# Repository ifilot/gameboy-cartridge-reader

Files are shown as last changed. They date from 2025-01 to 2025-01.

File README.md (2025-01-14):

# Gameboy Cartridge Reader






This project is a Gameboy cartridge reader designed around the Atmel ATmega32u4
microcontroller. It provides an easy way to interface with Gameboy cartridges,
enabling data reading, writing, and backup. The design includes a custom PCB,
firmware for the 32u4, and a simple GUI for user interaction.

> [!NOTE]
> Download a Windows 64-bit installer for the GUI [via this link](https://github.com/ifilot/gameboy-cartridge-reader/releases/latest/download/gbcr-installer-win64.exe)

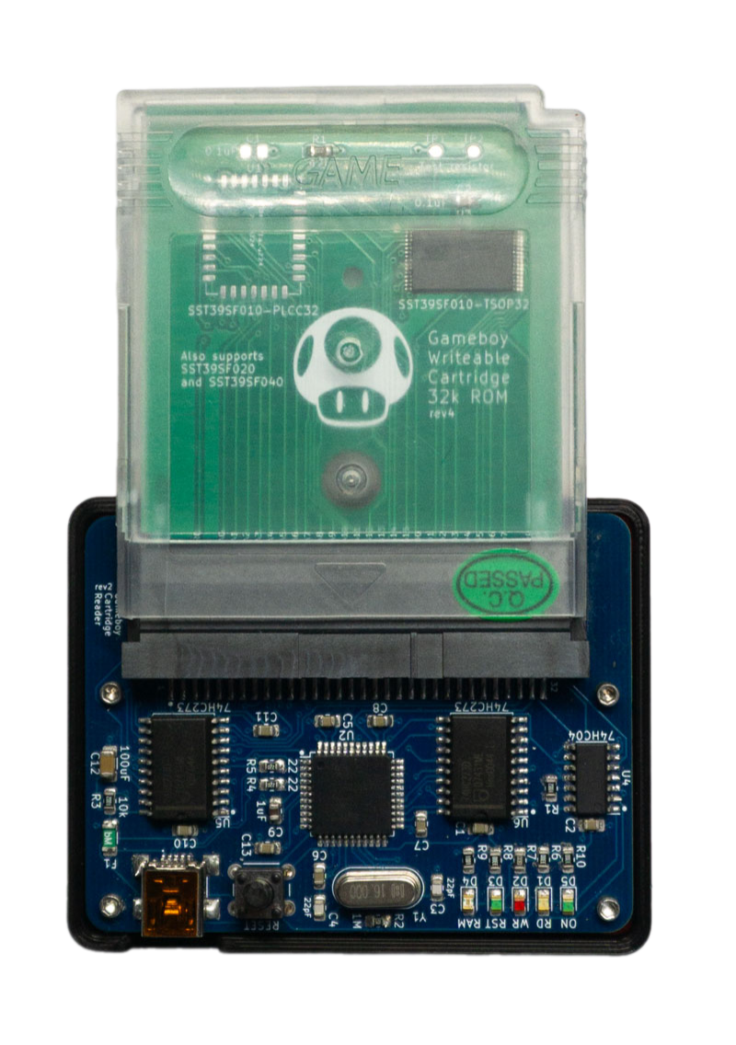
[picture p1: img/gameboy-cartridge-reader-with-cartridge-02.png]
PCB with components


## Features

* **Custom PCB**: Compact and optimized PCB designed for seamless connection with
  Gameboy cartridges and the 32u4.
* **Firmware**: Lightweight firmware written for the ATmega32u4, handling cartridge
  communication and USB interfacing.
* **GUI**: User-friendly graphical interface to manage cartridge data operations on
  your computer.
* **Open Source**: All design files, firmware, and GUI are open-source and available
  for modification.
* **Writable Cartridge Support**: Includes a [PCB design](pcb/gb-cart-sst39sf010/) 
  with an SST39SF010 chip, enabling the writing of 32KiB Gameboy games.
* **Gameboy Camera Support**: Easily extract photos taken with the 
  [Gameboy Camera](https://en.wikipedia.org/wiki/Game_Boy_Camera)
  and save them on your computer. The extracted images can be exported in a 
  variety of color palettes for a personalized look.

> [!IMPORTANT] 
> Please be aware of copyright laws regarding Gameboy and Gameboy
> Color games. Making copies of game data is strictly prohibited in many
> countries unless you own the original cartridge and are creating a backup for
> personal use where such actions are legally permitted. It is your
> responsibility to ensure compliance with local laws. This project is intended
> solely for **educational purposes** and **lawful personal** use.

## GUI

The GUI allows users to interact with their Gameboy cartridges through a
straightforward interface. Users can read ROM data from cartridges, create
backups of save files, and write new save files to supported cartridges.
Additionally, the GUI provides options for verifying data integrity, viewing
cartridge metadata (such as title and game ID), and managing writable cartridges
for flashing custom or homebrew games. Designed for simplicity, the GUI ensures
that all operations are intuitive and accessible, even for beginners.

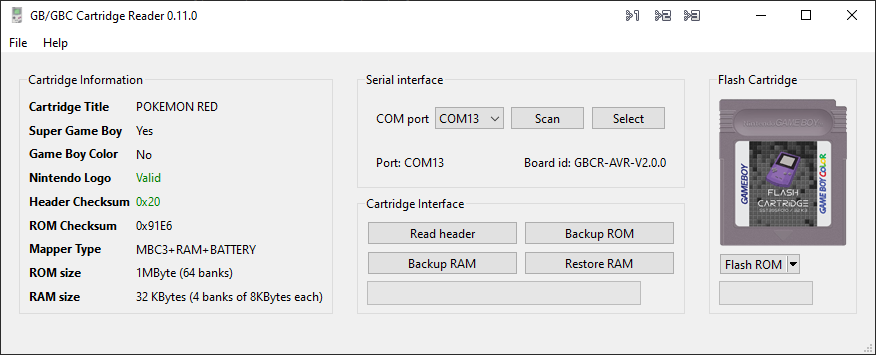
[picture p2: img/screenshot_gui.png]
Graphical User Interface


## Bundled games

The following games are bundled with the GUI and can be readily flashed by the
user to a writeable cartridge.

* [Quartet](https://makrill.itch.io/quartet)
* [Flappybird](https://github.com/pashutk/flappybird-gameboy)

## PCB

The PCB primarily utilizes SMD components, with the exception of the 16MHz
crystal and the push button, which are through-hole components. To simplify the
soldering process, it is recommended that users order a solder paste stencil and
use a hot plate to solder the SMD components efficiently and accurately.

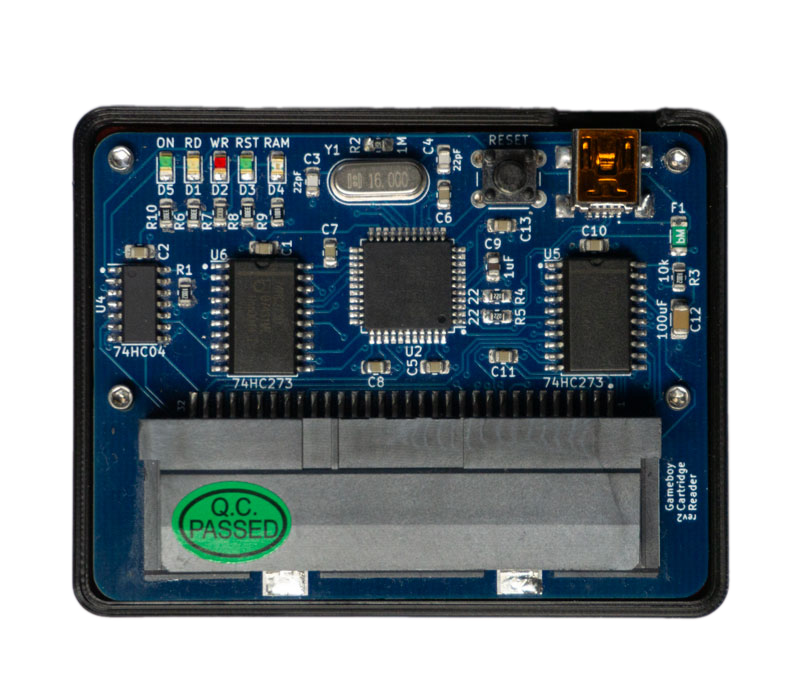
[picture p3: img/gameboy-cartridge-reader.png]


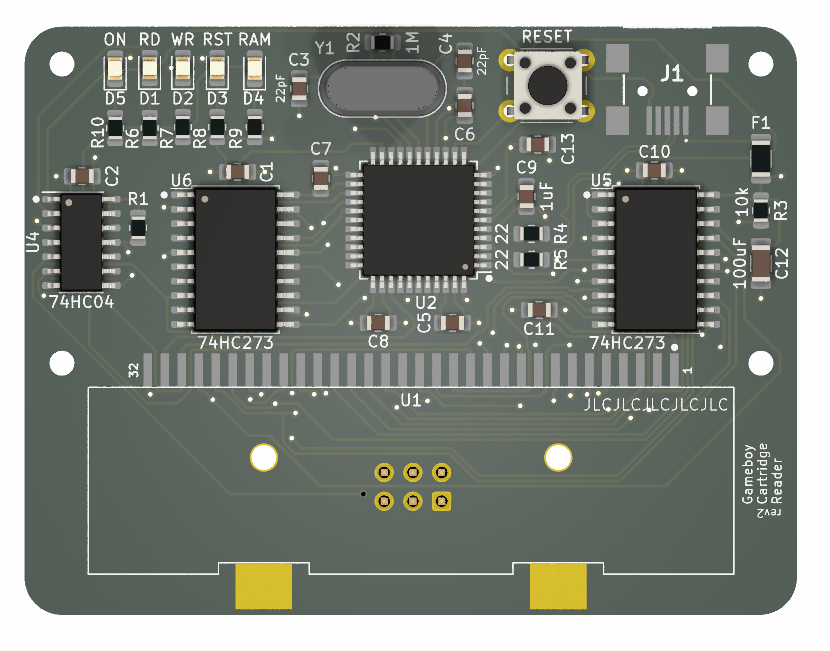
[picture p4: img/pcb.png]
PCB


### Schematic

PCB schematic

### Writeable cartridge

The writable cartridge for the Game Boy, based on the SST39SF010 flash memory
chip, offers versatile support for both TTSOP32 and PLCC32 package variants.
This flexibility allows developers and enthusiasts to choose their preferred
chip packaging without requiring additional hardware modifications. The
cartridge is designed to leverage the high-speed erase and write capabilities of
the SST39SF010, making it ideal for prototyping or homebrew games.

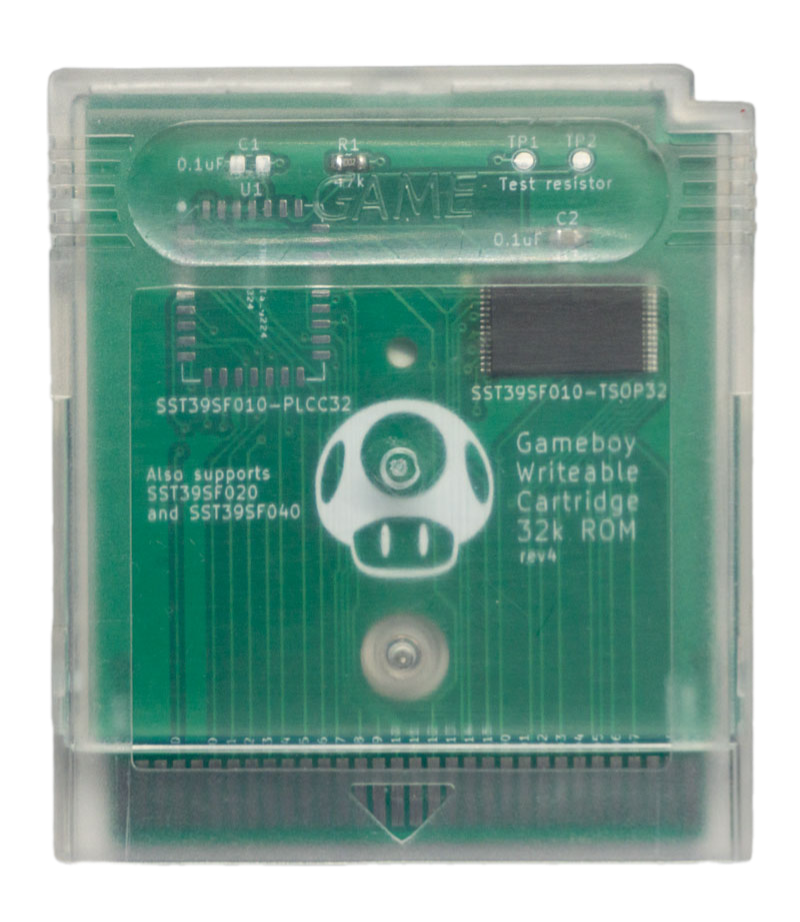
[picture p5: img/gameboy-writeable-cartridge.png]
Writeable cartridge


## Gameboy Camera Features

* Extract images directly from the Gameboy Camera cartridge.
* Customize the color scheme of the extracted photos.
* Preserve your Gameboy Camera creations in digital form.

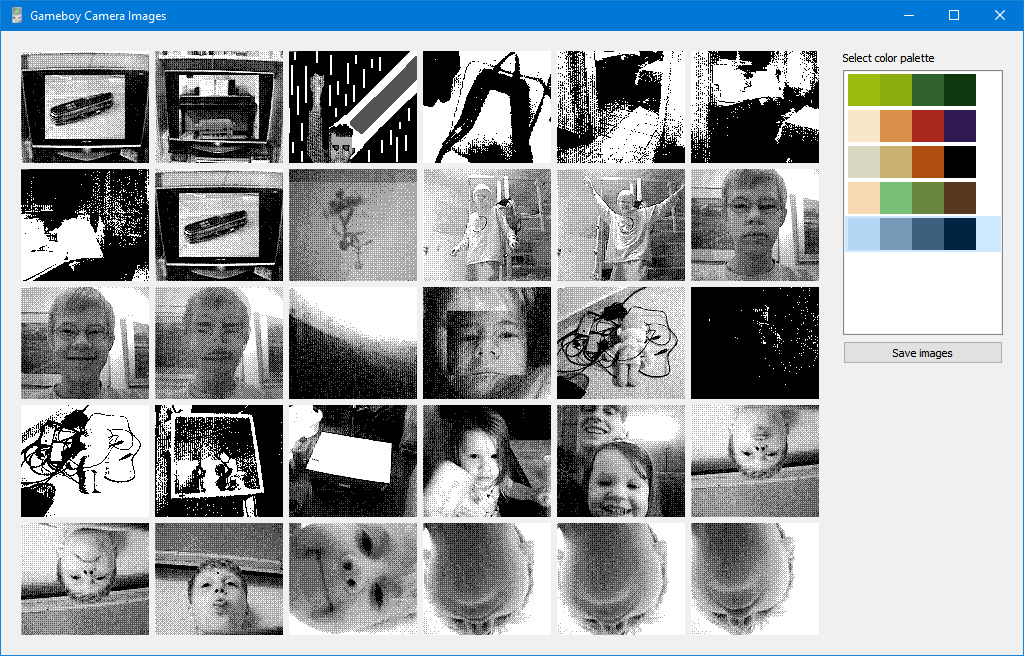
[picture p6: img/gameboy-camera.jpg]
Gameboy Camera


## Firmware

The firmware for the ATmega32u4 must be compiled using Atmel Studio to ensure
compatibility and proper optimization. Once compiled, the firmware can be
flashed to the microcontroller using an ISP programmer, such as AVRDUDE, for
seamless and reliable programming.

### Fuses

See the `firmware/<DEVICE>/scripts` folder for reading and writing the fuses. 
The proper fuse settings for `lfuse`, `hfuse` and `efuse` should 
be `0xFF`, `0xD8` and `0xCB`, respectively.

## Case

A 3D-printable case for the Gameboy cartridge reader is available in the
[cases](cases) folder, providing a protective and aesthetically pleasing
enclosure for the assembled PCB.

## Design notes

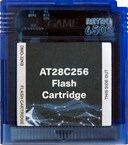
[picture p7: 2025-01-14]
gui/img/at28c256_flash_cartridge.png

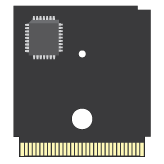
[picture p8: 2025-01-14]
gui/img/flash_cartridge_unknown.png

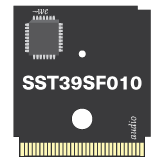
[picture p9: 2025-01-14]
gui/img/flash_cartridge_sst39sf010.png

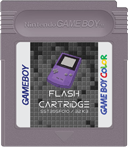
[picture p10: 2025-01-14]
gui/img/gameboy_cartridge_blank.png

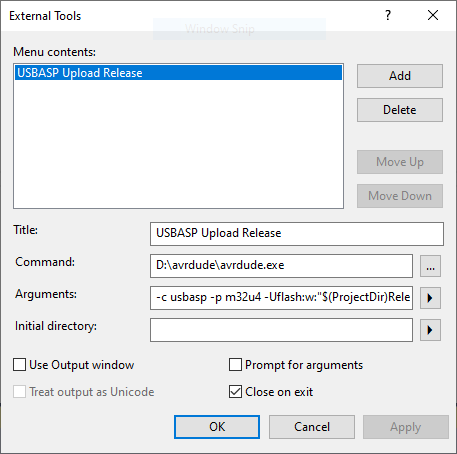
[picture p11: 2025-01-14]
img/screenshot_external_tool.PNG

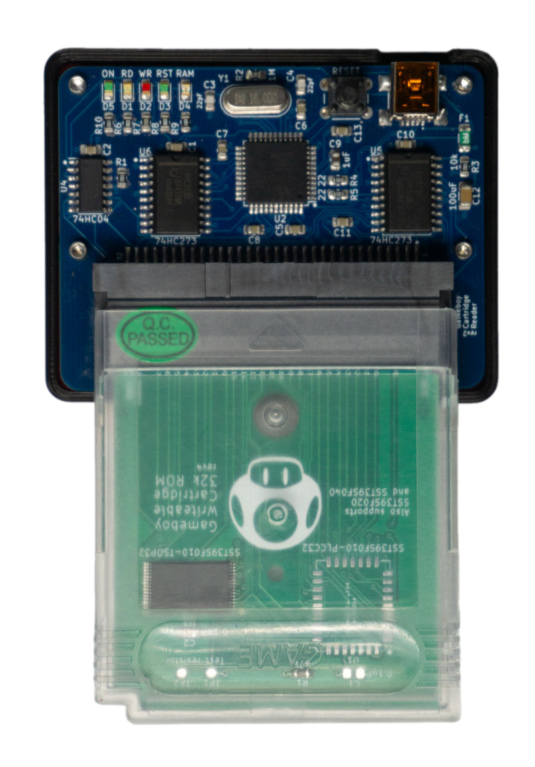
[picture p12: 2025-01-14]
img/gameboy-cartridge-reader-with-cartridge-01.png

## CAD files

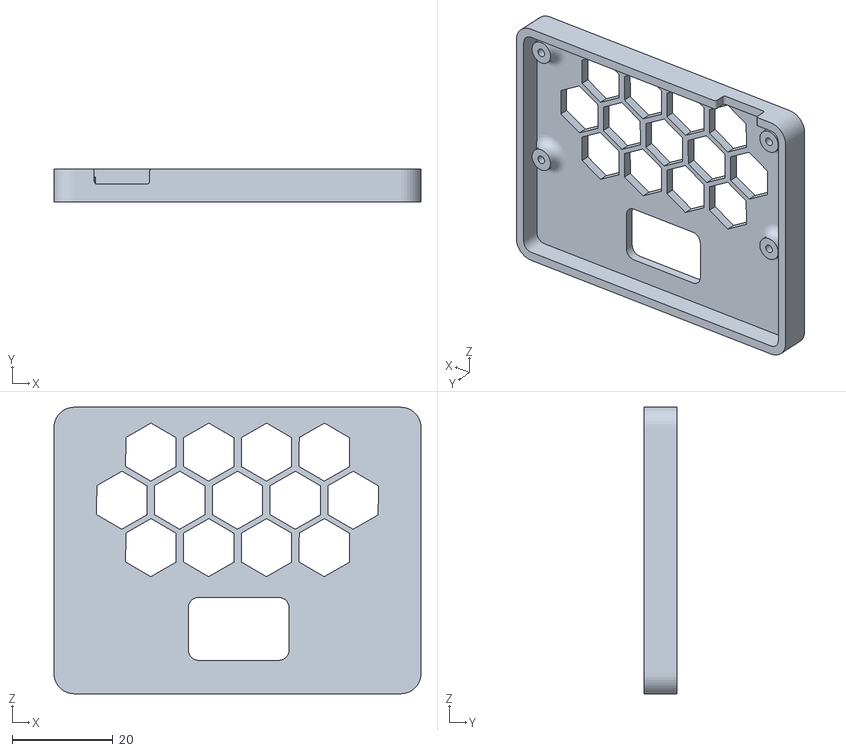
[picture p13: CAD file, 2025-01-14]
case/32u4/bottom_plate_32u4.stl
73.0 x 6.60 x 57.0

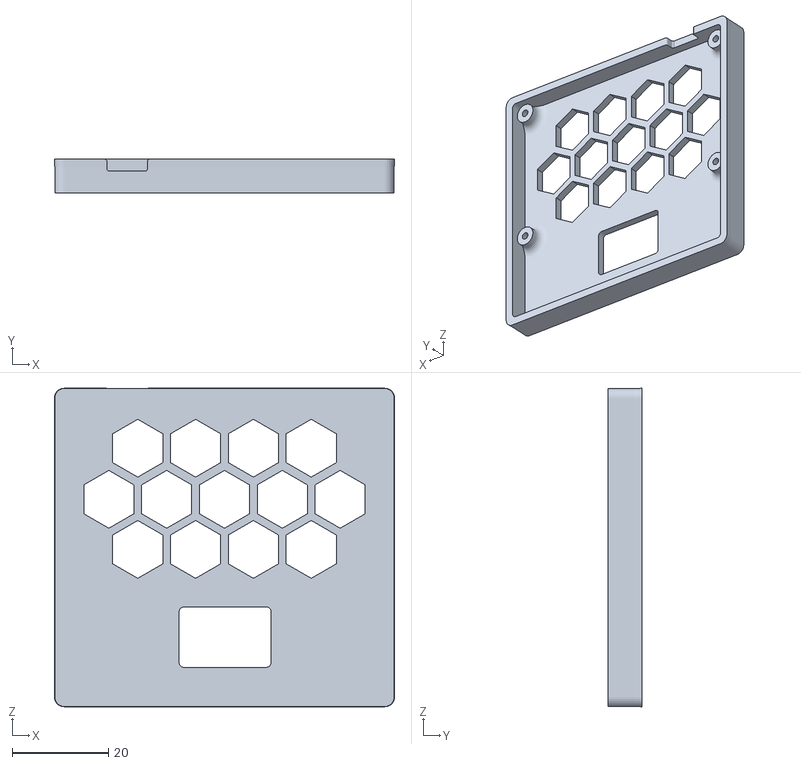
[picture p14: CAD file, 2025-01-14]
case/8515/bottom_plate_8515.stl
70.6 x 7.00 x 66.1

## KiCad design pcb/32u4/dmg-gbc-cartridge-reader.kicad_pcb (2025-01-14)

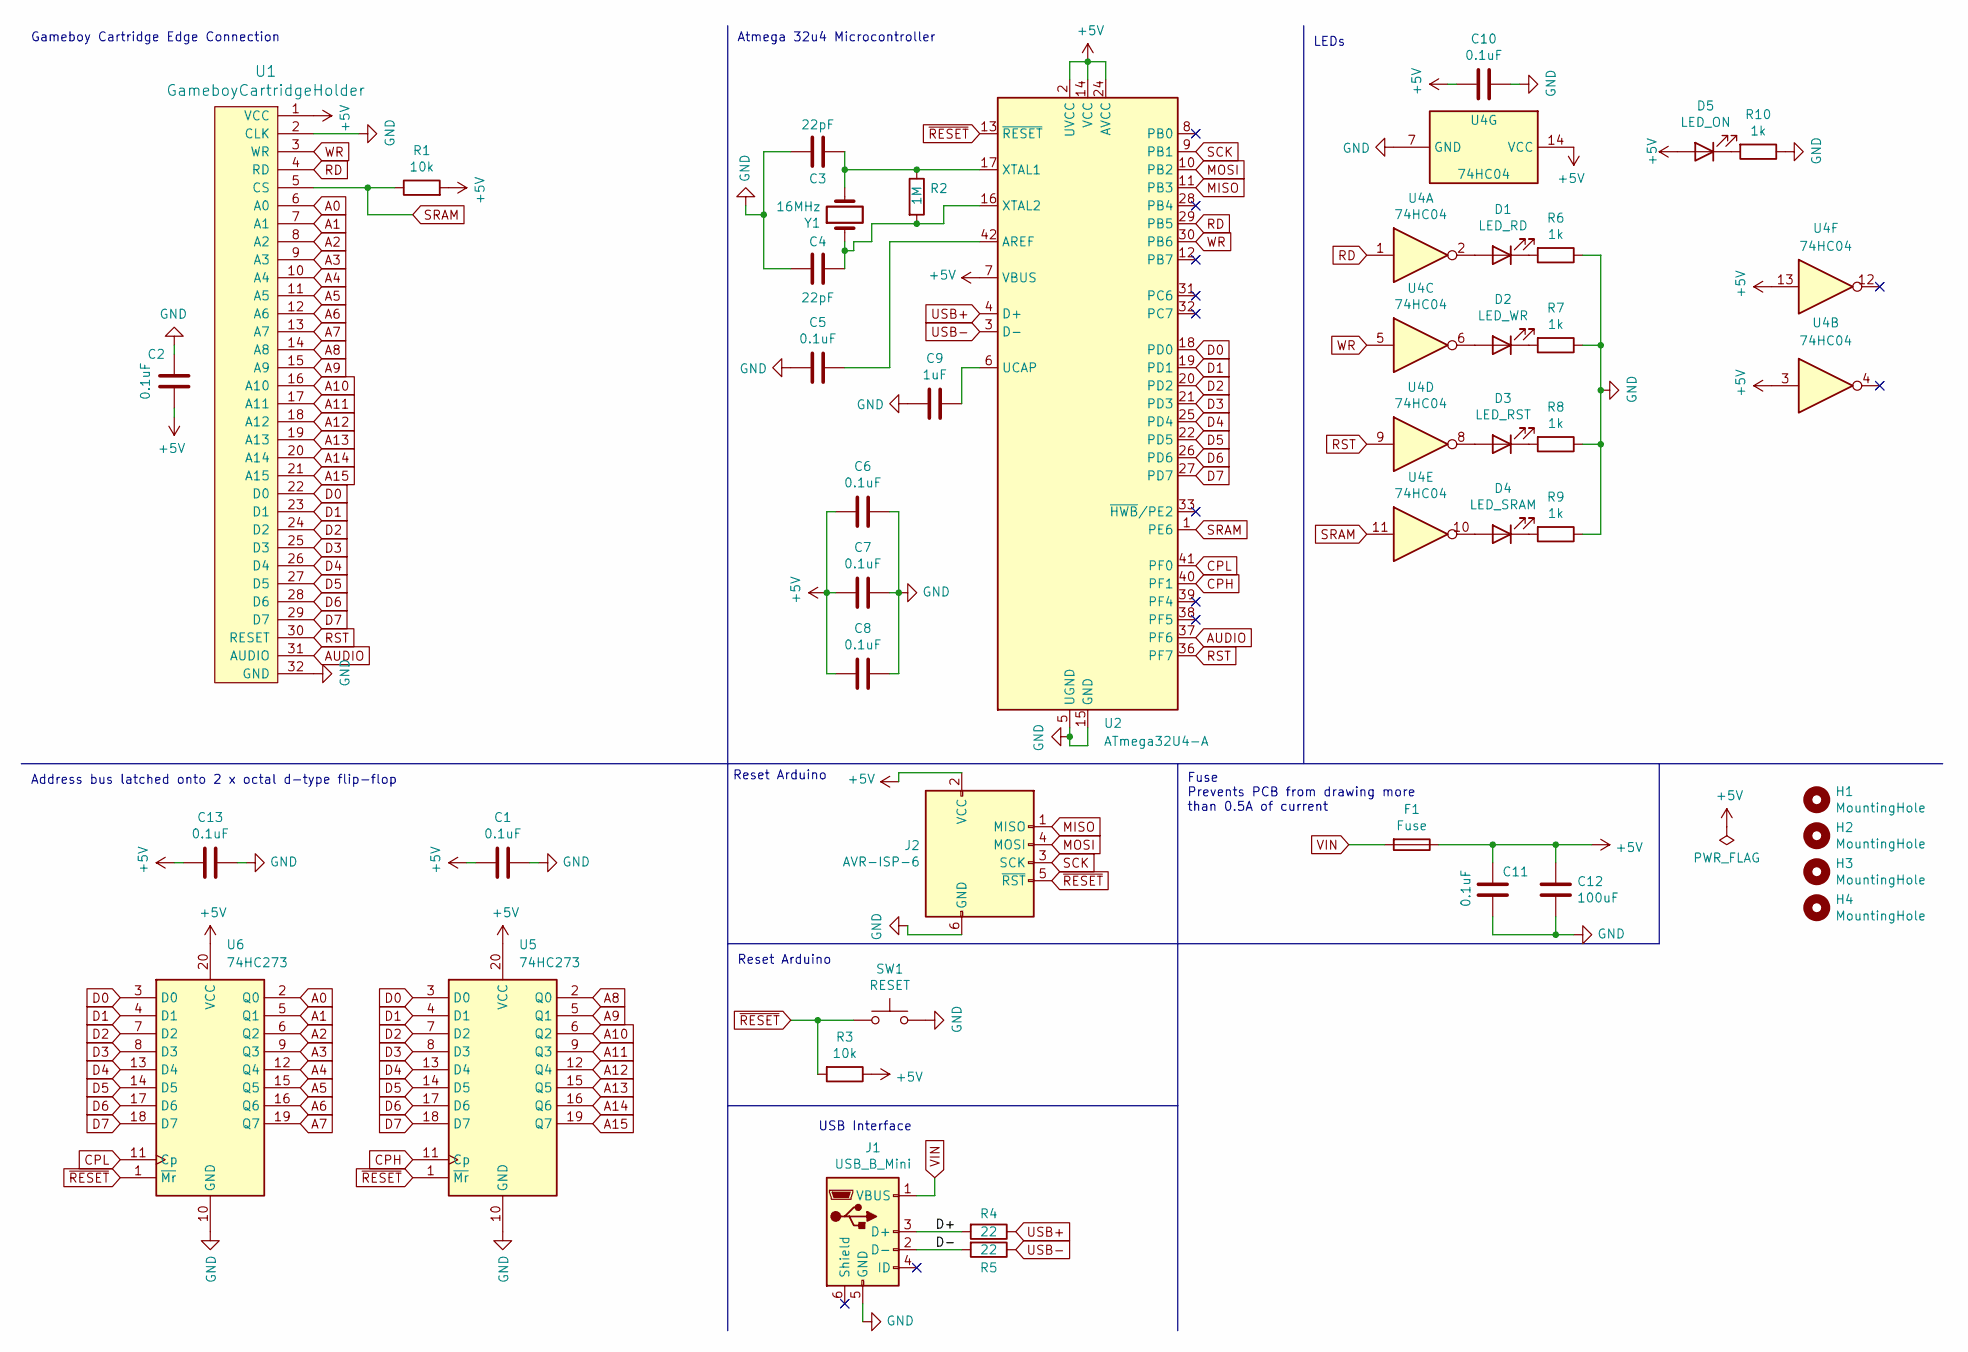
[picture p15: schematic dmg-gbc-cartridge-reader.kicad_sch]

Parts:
C1, C2, C5, C6, C7, C8, C10, C11, C13: 0.1uF; C_0805_2012Metric_Pad1.18x1.45mm_HandSolder; LCSC C49678
C3, C4: 22pF; C_0805_2012Metric_Pad1.18x1.45mm_HandSolder; LCSC C1804
C9: 1uF; C_0805_2012Metric_Pad1.18x1.45mm_HandSolder; LCSC C28323
C12: 100uF; C_1206_3216Metric_Pad1.33x1.80mm_HandSolder; LCSC C96123
D1: LED_RD; LED_0805_2012Metric_Pad1.15x1.40mm_HandSolder; LCSC C2296
D2: LED_WR; LED_0805_2012Metric_Pad1.15x1.40mm_HandSolder; LCSC C2296
D3: LED_RST; LED_0805_2012Metric_Pad1.15x1.40mm_HandSolder; LCSC C84256
D4: LED_SRAM; LED_0805_2012Metric_Pad1.15x1.40mm_HandSolder; LCSC C84256
D5: LED_ON; LED_0805_2012Metric_Pad1.15x1.40mm_HandSolder; LCSC C2297
F1: Fuse; R_1206_3216Metric_Pad1.30x1.75mm_HandSolder
H1, H2, H3, H4: MountingHole; MountingHole_2.2mm_M2
J1: USB_B_Mini; 65100516121
J2: AVR-ISP-6; IDC-Header_2x03_P2.54mm_Vertical
R1, R3: 10k; R_0805_2012Metric_Pad1.20x1.40mm_HandSolder; LCSC C17902
R2: 1M; R_0805_2012Metric_Pad1.20x1.40mm_HandSolder; LCSC C22935
R4, R5: 22; R_0805_2012Metric_Pad1.20x1.40mm_HandSolder; LCSC C23345
R6, R7, R8, R9, R10: 1k; R_0805_2012Metric_Pad1.20x1.40mm_HandSolder; LCSC C21190
SW1: RESET; SW_PUSH_6mm
U1: GameboyCartridgeHolder; GBA
U2: ATmega32U4-A; TQFP-44_10x10mm_P0.8mm
U4: 74HC04; SOIC-14_3.9x8.7mm_P1.27mm
U5, U6: 74HC273; SOIC-20W_7.5x12.8mm_P1.27mm
Y1: 16MHz; Crystal_HC49-U_Vertical; LCSC C13738

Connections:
+5V: C1.2, C2.2, C6.2, C7.2, C8.2, C10.2, C11.1, C12.1, C13.2, D5.2 (A), F1.1, J2.2 (VCC), R1.2, R3.1, U1.1 (VCC), U2.2 (UVCC), U2.7 (VBUS), U2.14 (VCC), U2.24 (AVCC), U2.34 (VCC), U2.44 (AVCC), U4.3, U4.13, U4.14 (VCC), U5.20 (VCC), U6.20 (VCC)
/D+: J1.3 (D+), R4.2
/D-: J1.2 (D-), R5.2
A0: U1.6 (A0), U6.2 (Q0)
A1: U1.7 (A1), U6.5 (Q1)
A2: U1.8 (A2), U6.6 (Q2)
A3: U1.9 (A3), U6.9 (Q3)
A4: U1.10 (A4), U6.12 (Q4)
A5: U1.11 (A5), U6.15 (Q5)
A6: U1.12 (A6), U6.16 (Q6)
A7: U1.13 (A7), U6.19 (Q7)
A8: U1.14 (A8), U5.2 (Q0)
A9: U1.15 (A9), U5.5 (Q1)
A10: U1.16 (A10), U5.6 (Q2)
A11: U1.17 (A11), U5.9 (Q3)
A12: U1.18 (A12), U5.12 (Q4)
A13: U1.19 (A13), U5.15 (Q5)
A14: U1.20 (A14), U5.16 (Q6)
A15: U1.21 (A15), U5.19 (Q7)
AUDIO: U1.31 (AUDIO), U2.37 (PF6)
CPH: U2.40 (PF1), U5.11 (Cp)
CPL: U2.41 (PF0), U6.11 (Cp)
D0: U1.22 (D0), U2.18 (PD0), U5.3 (D0), U6.3 (D0)
D1: U1.23 (D1), U2.19 (PD1), U5.4 (D1), U6.4 (D1)
D2: U1.24 (D2), U2.20 (PD2), U5.7 (D2), U6.7 (D2)
D3: U1.25 (D3), U2.21 (PD3), U5.8 (D3), U6.8 (D3)
D4: U1.26 (D4), U2.25 (PD4), U5.13 (D4), U6.13 (D4)
D5: U1.27 (D5), U2.22 (PD5), U5.14 (D5), U6.14 (D5)
D6: U1.28 (D6), U2.26 (PD6), U5.17 (D6), U6.17 (D6)
D7: U1.29 (D7), U2.27 (PD7), U5.18 (D7), U6.18 (D7)
GND: C1.1, C2.1, C3.1, C4.1, C5.2, C6.1, C7.1, C8.1, C9.2, C10.1, C11.2, C12.2, C13.1, J1.5 (GND), J2.6 (GND), R6.1, R7.1, R8.1, R9.1, R10.1, SW1.2, U1.2 (CLK), U1.32 (GND), U2.5 (UGND), U2.15 (GND), U2.23 (GND), U2.35 (GND), U2.43 (GND), U4.7 (GND), U5.10 (GND), U6.10 (GND)
MISO: J2.1 (MISO), U2.11 (PB3)
MOSI: J2.4 (MOSI), U2.10 (PB2)
unnamed: D1.2 (A), U4.2
unnamed: D1.1 (K), R6.2
unnamed: D2.2 (A), U4.6
unnamed: D2.1 (K), R7.2
unnamed: D3.2 (A), U4.8
unnamed: D3.1 (K), R8.2
unnamed: D4.2 (A), U4.10
unnamed: D4.1 (K), R9.2
unnamed: D5.1 (K), R10.2
unnamed: C5.1, U2.42 (AREF)
unnamed: C9.1, U2.6 (UCAP)
unnamed: C3.2, R2.1, U2.17 (XTAL1), Y1.2
unnamed: C4.2, R2.2, U2.16 (XTAL2), Y1.1
RD: U1.4 (RD), U2.29 (PB5), U4.1
RST: U1.30 (RESET), U2.36 (PF7), U4.9
SCK: J2.3 (SCK), U2.9 (PB1)
SRAM: R1.1, U1.5 (CS), U2.1 (PE6), U4.11
USB+: R4.1, U2.4 (D+)
USB-: R5.1, U2.3 (D-)
VIN: F1.2, J1.1 (VBUS)
WR: U1.3 (WR), U2.30 (PB6), U4.5
~RESET: J2.5 (~RST), R3.2, SW1.1, U2.13 (~RESET), U5.1 (~Mr), U6.1 (~Mr)

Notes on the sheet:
Address bus latched onto 2 x octal d-type flip-flop
Reset Arduino
Atmega 32u4 Microcontroller
LEDs
Gameboy Cartridge Edge Connection
USB Interface
Fuse Prevents PCB from drawing more than 0.5A of current

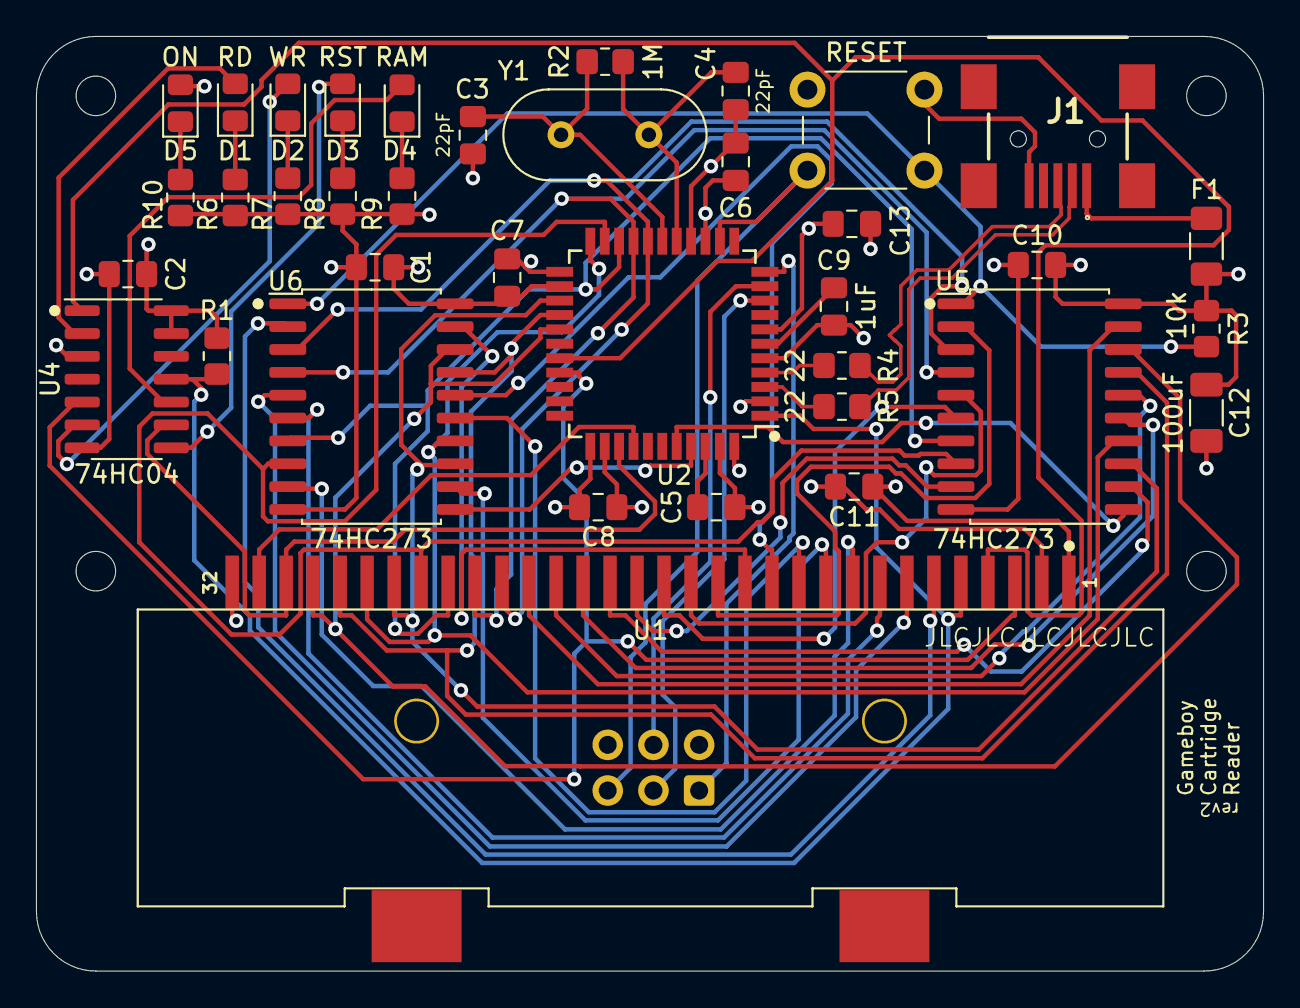
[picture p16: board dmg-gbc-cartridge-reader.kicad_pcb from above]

Board: 4 copper layers, 68.2 x 51.9 mm, 42 parts (1 on the bottom side), 55 nets.

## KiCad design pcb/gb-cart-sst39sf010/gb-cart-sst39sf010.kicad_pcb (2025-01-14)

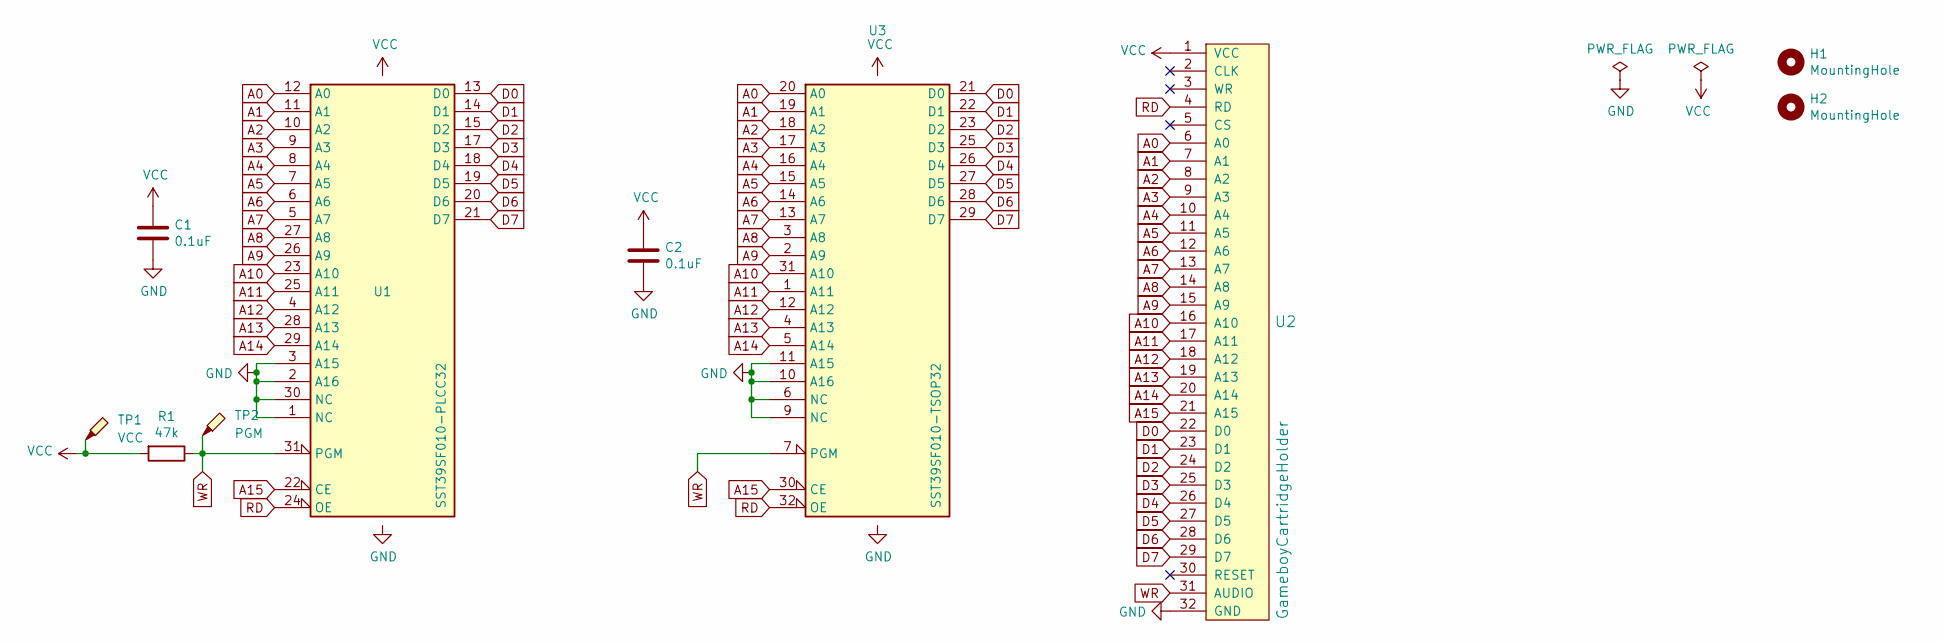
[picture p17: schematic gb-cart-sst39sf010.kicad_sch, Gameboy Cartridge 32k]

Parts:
C1, C2: 0.1uF; C_0805_2012Metric_Pad1.18x1.45mm_HandSolder
H1: MountingHole; MountingHole_7.2mm
H2: MountingHole; MountingHole_2.3mm
R1: 47k; R_0805_2012Metric_Pad1.20x1.40mm_HandSolder
TP1: VCC; TestPoint_Pad_D1.5mm
TP2: PGM; TestPoint_Pad_D1.5mm
U1: SST39SF010-PLCC32; PLCC-32_11.4x14.0mm_P1.27mm
U2: GameboyCartridgeHolder; GameBoy_Cartridge_1x32_P1.50mm_Edge
U3: SST39SF010-TSOP32; TSOP-I-32_11.8x8mm_P0.5mm

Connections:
A0: U1.12 (A0), U2.6 (A0), U3.20 (A0)
A1: U1.11 (A1), U2.7 (A1), U3.19 (A1)
A2: U1.10 (A2), U2.8 (A2), U3.18 (A2)
A3: U1.9 (A3), U2.9 (A3), U3.17 (A3)
A4: U1.8 (A4), U2.10 (A4), U3.16 (A4)
A5: U1.7 (A5), U2.11 (A5), U3.15 (A5)
A6: U1.6 (A6), U2.12 (A6), U3.14 (A6)
A7: U1.5 (A7), U2.13 (A7), U3.13 (A7)
A8: U1.27 (A8), U2.14 (A8), U3.3 (A8)
A9: U1.26 (A9), U2.15 (A9), U3.2 (A9)
A10: U1.23 (A10), U2.16 (A10), U3.31 (A10)
A11: U1.25 (A11), U2.17 (A11), U3.1 (A11)
A12: U1.4 (A12), U2.18 (A12), U3.12 (A12)
A13: U1.28 (A13), U2.19 (A13), U3.4 (A13)
A14: U1.29 (A14), U2.20 (A14), U3.5 (A14)
A15: U1.22 (CE), U2.21 (A15), U3.30 (CE)
D0: U1.13 (D0), U2.22 (D0), U3.21 (D0)
D1: U1.14 (D1), U2.23 (D1), U3.22 (D1)
D2: U1.15 (D2), U2.24 (D2), U3.23 (D2)
D3: U1.17 (D3), U2.25 (D3), U3.25 (D3)
D4: U1.18 (D4), U2.26 (D4), U3.26 (D4)
D5: U1.19 (D5), U2.27 (D5), U3.27 (D5)
D6: U1.20 (D6), U2.28 (D6), U3.28 (D6)
D7: U1.21 (D7), U2.29 (D7), U3.29 (D7)
GND: C1.2, C2.2, U1.1 (NC), U1.2 (A16), U1.3 (A15), U1.16 (GND), U1.30 (NC), U2.32 (GND), U3.6 (NC), U3.9 (NC), U3.10 (A16), U3.11 (A15), U3.24 (GND)
RD: U1.24 (OE), U2.4 (RD), U3.32 (OE)
VCC: C1.1, C2.1, R1.2, TP1.1, U1.32 (VCC), U2.1 (VCC), U3.8 (VCC)
WR: R1.1, TP2.1, U1.31 (PGM), U2.31 (AUDIO), U3.7 (PGM)

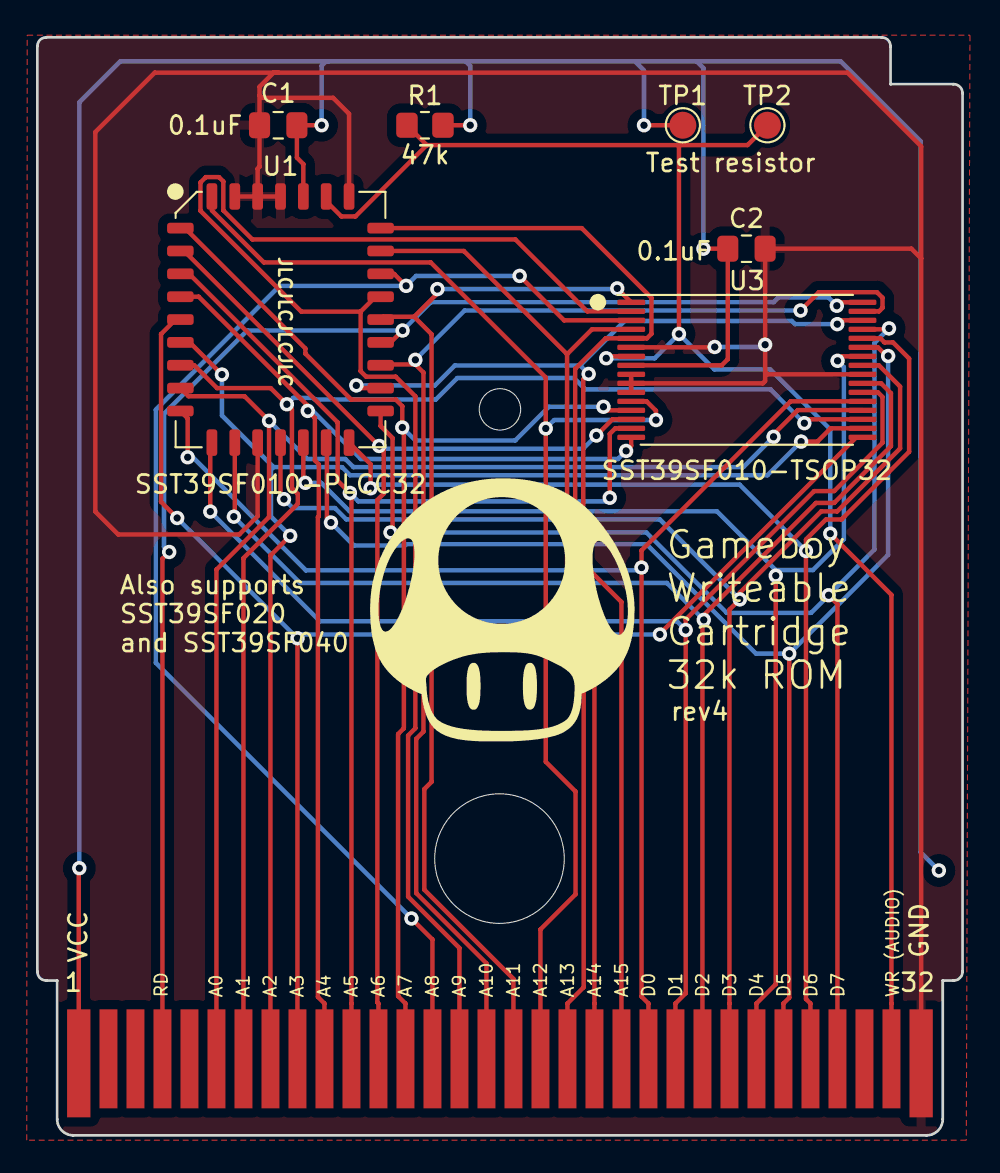
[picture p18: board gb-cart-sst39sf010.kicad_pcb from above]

Board: 2 copper layers, 51.4 x 61.0 mm, 11 parts (0 on the bottom side), 28 nets.

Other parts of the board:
G0001: LOGO; mushroom

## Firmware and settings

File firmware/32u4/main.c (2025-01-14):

#include <avr/io.h>
#include <avr/eeprom.h> 
#include <util/delay.h>
#include <stdlib.h>

#include "VirtualSerial.h"

// list of defines for easy toggling of pins
#define READ_HIGH		PORTB |= (1 << 5)
#define READ_LOW		PORTB &= ~(1 << 5)
#define WRITE_HIGH		PORTB |= (1 << 6)
#define WRITE_LOW		PORTB &= ~(1 << 6)
#define WRITE_PULSE     {WRITE_LOW;WRITE_HIGH;}    // triggered on falling edge   
#define SRAM_HIGH       PORTE |= (1 << 6)
#define SRAM_LOW        PORTE &= ~(1 << 6)
#define RESET_HIGH      PORTF |= (1 << 7)
#define RESET_LOW		PORTF &= ~(1 << 7)
#define AUDIO_HIGH      PORTF |= (1 << 6)
#define AUDIO_LOW       PORTF &= ~(1 << 6)
#define AUDIO_PULSE     {AUDIO_LOW; AUDIO_HIGH;}    // triggered on falling edge   
#define CPL_HIGH		PORTF |= (1 << 0)
#define CPL_LOW			PORTF &=  ~(1 << 0)
#define CPL_TOGGLE		{CPL_HIGH; CPL_LOW;}		// triggered on rising edge
#define CPH_HIGH		PORTF |= (1 << 1)
#define CPH_LOW			PORTF &=  ~(1 << 1)
#define CPH_TOGGLE		{CPH_HIGH; CPH_LOW;}		// triggered on rising edge
#define CRST_HIGH		PORTB |= (1 << 7)
#define CRST_LOW		PORTB &= ~(1 << 7)
#define CRST_PULSE      {CRST_HIGH; CRST_LOW;}		// triggered on rising edge
#define PINS_INPUT		{DDRD = 0x00; PORTD = 0x00;}
#define PINS_OUTPUT     DDRD = 0xFF
#define WAIT2			{asm volatile("nop");asm volatile("nop");}
#define WAIT4			{WAIT2;WAIT2}
#define WAIT6			{WAIT4;WAIT2}
#define WAIT			WAIT2

// macro to suppress unused variable
#define UNUSED(x) (void)(x)

// LUFA CDC Class driver interface configuration
USB_ClassInfo_CDC_Device_t VirtualSerial_CDC_Interface =
	{
		.Config =
			{
				.ControlInterfaceNumber   = INTERFACE_ID_CDC_CCI,
				.DataINEndpoint           =
					{
						.Address          = CDC_TX_EPADDR,
						.Size             = CDC_TXRX_EPSIZE,
						.Banks            = 1,
					},
				.DataOUTEndpoint =
					{
						.Address          = CDC_RX_EPADDR,
						.Size             = CDC_TXRX_EPSIZE,
						.Banks            = 1,
					},
				.NotificationEndpoint =
					{
						.Address          = CDC_NOTIFICATION_EPADDR,
						.Size             = CDC_NOTIFICATION_EPSIZE,
						.Banks            = 1,
					},
			},
	};

// standard file stream
static FILE USBSerialStream;

// board id and compile time statistics
static const char board_id[17] = {'G','B','C','R','-','A','V','R','-','V','2','.','0','.','0','\0'};
static const char cdate[17] = __DATE__;
static const char ctime[17] = __TIME__;

// command storage
char instruction[9];    // stores single 8-byte instruction
uint8_t inptr = 0;      // instruction pointer

// forward declaration
void write_board_id(void);
void compile_time();
void parse_instructions(void);
void read_header(void);
void set_upper_address(uint8_t);
void set_lower_address(uint8_t);
void read_sector(uint16_t addr);
void write_byte_at_address(uint16_t addr, uint8_t val);
void set_ram_enable(bool enable);
void write_bytes_ram(uint16_t addr, uint16_t sz);

// flashable cartridges
void sst39sf0x0_get_device_id(void);
uint16_t sst39sf0x0_pollbyte(uint16_t addr);
void sst39sf0x0_erase_sector(uint16_t erase_sector);
void sst39sf0x0_write_block(uint16_t);

int main(void) {
	SetupHardware();

	/* Create a regular character stream for the interface so that it can be used with the stdio.h functions */
	CDC_Device_CreateStream(&VirtualSerial_CDC_Interface, &USBSerialStream);

	GlobalInterruptEnable();

	for (;;)
	{
		/* Must throw away unused bytes from the host, or it will lock up while waiting for the device */
		if(CDC_Device_BytesReceived(&VirtualSerial_CDC_Interface) > 0) {
			char c = CDC_Device_ReceiveByte(&VirtualSerial_CDC_Interface);
			
			// only capture alphanumerical data
			if((c >= 48 && c <= 57) || (c >= 65 && 90)) {
				instruction[inptr] = c;
				inptr++;
			}
			
			if(inptr == 8) {
				parse_instructions();
				inptr = 0;
			}
		}

		// handle USB Tasks
		CDC_Device_USBTask(&VirtualSerial_CDC_Interface);
		USB_USBTask();
	}
}

/*
 * @brief Put pins in their default configuration
 */
void reset_pins() {
	READ_HIGH;
	WRITE_HIGH;
	SRAM_HIGH;
	RESET_HIGH;
	CPL_LOW;
	CPH_LOW;
	AUDIO_HIGH; // set audio high as it is connected to ~WE signal
	PINS_INPUT;
}

void SetupHardware(void) {
	DDRB = 0xFF;	  // output
	DDRD = 0x00;	  // input
	PINS_INPUT;
	DDRE |= (1 << 6); // output on SRAM
	DDRF = 0xFF;	  // output
	
	reset_pins();
	
	MCUSR &= ~(1 << WDRF);
	wdt_disable();

	clock_prescale_set(clock_div_1);

	/* Hardware Initialization */
	USB_Init();
}

void EVENT_USB_Device_Connect(void) {
	// do nothing
}

void EVENT_USB_Device_Disconnect(void) {
	// do nothing
}

void EVENT_USB_Device_ConfigurationChanged(void) {
	bool ConfigSuccess = true;

	ConfigSuccess &= CDC_Device_ConfigureEndpoints(&VirtualSerial_CDC_Interface);
}

void EVENT_USB_Device_ControlRequest(void) {
	CDC_Device_ProcessControlRequest(&VirtualSerial_CDC_Interface);
}

void EVENT_CDC_Device_ControLineStateChanged(USB_ClassInfo_CDC_Device_t *const CDCInterfaceInfo) {
	bool HostReady = (CDCInterfaceInfo->State.ControlLineStates.HostToDevice & CDC_CONTROL_LINE_OUT_DTR) != 0;
	UNUSED(HostReady);
}

void echo_command(void) {
	for(uint8_t i=0; i<8; i++) {
		CDC_Device_SendByte(&VirtualSerial_CDC_Interface, instruction[i]);
	}
	CDC_Device_Flush(&VirtualSerial_CDC_Interface);
}

/*
 * @brief Check if part of two strings are equal
 * @param original string
 * @param reference string
 * @param offset in original string
 * @param length to read
 */
bool check_command(const char* cmd, const char* ref, uint8_t offset, uint8_t length) {
	for(uint8_t i=0; i<length; i++) {
		if(cmd[i+offset] != ref[i]) {
			return false;
		}
	}
	return true;
}

/*
 * @brief convert 4 HEX bytes of instruction to 16 bit unsigned integer
 * @param command word
 * @param offset in command
 */
uint16_t get_uint16(const char* instruction, uint8_t offset) {
	char buffer[5];
	memcpy(buffer, &instruction[offset], 4);
	buffer[4] = '\0';
	return strtoul(buffer, NULL, 16);
}

/*
 * @brief convert 2 HEX bytes of instruction to 8 bit unsigned integer
 * @param command word
 * @param offset in command
 */
uint8_t get_uint8(const char* instruction, uint8_t offset) {
	char buffer[3];
	buffer[0] = instruction[offset];
	buffer[1] = instruction[offset+1];
	buffer[2] = '\0';
	return strtoul(buffer, NULL, 16);
}

/*
 * @brief parse instructions received over serial
 */
void parse_instructions(void) {
	echo_command();
	
	if(check_command(instruction, "READINFO", 0, 8)) {
		write_board_id();
		return;
	}  else if(check_command(instruction, "COMPTIME", 0, 8)) {
		compile_time();
		return;
	} else if(check_command(instruction, "READHDR0", 0, 8)) {
		read_header();
		return;
	} else if(check_command(instruction, "DEVIDSST", 0, 8)) {
		sst39sf0x0_get_device_id();
		return;
	} else if(check_command(instruction, "RAMON000", 0, 8)) {
		set_ram_enable(true);
		return;
	} else if(check_command(instruction, "RAMOFF00", 0, 8)) {
		set_ram_enable(false);
		return;
	} else if(check_command(instruction, "RMWR2k00", 0, 8)) {
		write_bytes_ram(0xA000, 2048);
		return;
	} else if(check_command(instruction, "RMWR4kA0", 0, 8)) {
		write_bytes_ram(0xA000, 4096);
		return;
	} else if(check_command(instruction, "RMWR4kB0", 0, 8)) {
		write_bytes_ram(0xB000, 4096);
		return;
	} else if(check_command(instruction, "RDBK", 0, 4)) {
		read_sector(get_uint16(instruction, 4));
		return;
	} else if(check_command(instruction, "WRST", 0, 4)) {
		clock_prescale_set(clock_div_2);
		sst39sf0x0_write_block(get_uint16(instruction, 4));
		clock_prescale_set(clock_div_1);
		return;
	} else if(check_command(instruction, "ESST", 0, 4)) {
		sst39sf0x0_erase_sector(get_uint16(instruction, 4));
		return;
	} else if(check_command(instruction, "WR", 0, 2)) {
		write_byte_at_address(get_uint16(instruction, 2), get_uint8(instruction, 6));
		return;
	}
}

/*
 * @brief Write board ID to serial
 */
void write_board_id(void) {
	for(uint8_t i=0; i<16; i++) {
		CDC_Device_SendByte(&VirtualSerial_CDC_Interface, board_id[i]);
	}
}

/*
 * @brief Yield compile time
 */
void compile_time() {
	for(uint8_t i=0; i<16; i++) {
		CDC_Device_SendByte(&VirtualSerial_CDC_Interface, cdate[i]);
	}
	for(uint8_t i=0; i<16; i++) {
		CDC_Device_SendByte(&VirtualSerial_CDC_Interface, ctime[i]);
	}
}

/*
 * @brief Set upper eight bits of the address
 * @param address
 */
void set_upper_address(uint8_t addr) {
	PINS_OUTPUT;
	PORTD = addr;
	CPH_TOGGLE;
	PINS_INPUT;
}

/*
 * @brief Set lower eight bits of the address
 * @param address
 */
void set_lower_address(uint8_t addr) {
	PINS_OUTPUT;
	PORTD = addr;
	CPL_TOGGLE;
	PINS_INPUT;
}

/*
 * @brief Set address
 * @param address
 */
void set_address(uint16_t addr) {
	set_upper_address(addr >> 8);
	set_lower_address(addr & 0xFF);
}

/*
 * @brief Read cartridge header
 *
 * Read the first 0x150 bytes of the cartridge
 */
void read_header() {
		
	for(uint16_t i=0; i<0x150; i++) {
		set_address(i);
		READ_LOW;	// note that these two NOPs are absolutely necessary to give the 32u4 enough time to sample the ROM
		asm volatile("nop");
		asm volatile("nop"); 
		CDC_Device_SendByte(&VirtualSerial_CDC_Interface, (uint8_t)PIND);
		READ_HIGH;
	}
}

/*
 * @brief Read a sector of 0x1000 bytes of the cartridge
 * @param starting address
 *
 * Read 0x1000 bytes starting at address addr; note that
 * the lower 12 bits of the address need to be zero
 * 
 */
void read_sector(uint16_t addr) {
	for(uint8_t j=0; j<0x10; j++) {
		set_upper_address((uint8_t)(addr >> 8) + j);
		
		uint8_t i = 0;
		do {
			set_lower_address(i);
			READ_LOW;	// note that these two NOPs are absolutely necessary to give the 32u4 enough time to sample the ROM
			asm volatile("nop");
			asm volatile("nop");
			CDC_Device_SendByte(&VirtualSerial_CDC_Interface, (uint8_t)PIND);
			READ_HIGH;
		} while(i++ != 255);
		
		CDC_Device_Flush(&VirtualSerial_CDC_Interface);
	}
}

/*
 * @brief Enable or disable RAM banks
 * @param Whether to enable or disable ram
 */
void set_ram_enable(bool enable) {
	if(enable) {
		write_byte_at_address(0x0000, 0x0A);
		SRAM_LOW;
	} else {
		write_byte_at_address(0x0000, 0x00);
		SRAM_HIGH;
	}
}

/*
 * @brief Write bytes to RAM
 * @param number of bytes to write (typically 2kb or 4kb)
 *
 * Write sz bytes to RAM memory
 */
void write_bytes_ram(uint16_t addr, uint16_t sz) {		
	uint8_t nrblocks = sz / 0x100;
	for(uint8_t j=0; j<nrblocks; j++) {
		set_upper_address((uint8_t)(addr >> 8) + j);
		uint8_t i = 0;
		do {
			set_lower_address(i);
			PINS_OUTPUT;
			
			// keep on looping until a byte is read
			while(true) {
				if(CDC_Device_BytesReceived(&VirtualSerial_CDC_Interface) > 0) {
					// once byte is read, write it to RAM
					PORTD = CDC_Device_ReceiveByte(&VirtualSerial_CDC_Interface);
					WRITE_LOW;
					asm volatile("nop");
					asm volatile("nop");
					asm volatile("nop");
					asm volatile("nop");
					WRITE_HIGH;
					break;
				}
			}
		} while(i++ != 255);
	}
	
	// set PORTD back to default input state
	PINS_INPUT;
}

/*
 * @brief Write a single byte at address
 * @param address to write byte
 * @param value to write
 *
 * This function is mainly used for bank switching, for
 * writing data to RAM or to flash, single-byte write
 * operations take too much time.
 */
void write_byte_at_address(uint16_t addr, uint8_t val) {
	set_address(addr);
	PINS_OUTPUT;

	PORTD = val;
	WRITE_PULSE; // pulse write signal
	
	PINS_INPUT;
}

/*
 * @brief Write single command word to SST39sf0x0 chip
 * @param address to write byte at
 * @param byte to write
 */
void sst39sf0x0_write_command(uint16_t addr, uint8_t val) {
	set_address(addr & (~(1 << 15)));	// set address and set low
	
	PINS_OUTPUT;						// write out
	PORTD = val;
	AUDIO_LOW;							// write address
	WAIT;
	AUDIO_HIGH;							// latch data
	set_address(addr | (1 << 15));		// set CE high
}

/*
 * @brief Get device ID from SST39SF0x0 chip
 */
void sst39sf0x0_get_device_id() {
	sst39sf0x0_write_command(0x5555, 0xAA);
	sst39sf0x0_write_command(0x2AAA, 0x55);
	sst39sf0x0_write_command(0x5555, 0x90);
	
	PINS_INPUT;
	set_address(0x0000);
	READ_LOW;
	WAIT;
	uint8_t id1 = PIND;
	READ_HIGH;
	
	set_lower_address(0x01);
	READ_LOW;
	WAIT;
	uint8_t id2 = PIND;
	READ_HIGH;
	
	sst39sf0x0_write_command(0x5555, 0xAA);
	sst39sf0x0_write_command(0x2AAA, 0x55);
	sst39sf0x0_write_command(0x5555, 0xF0);
	
	CDC_Device_SendByte(&VirtualSerial_CDC_Interface, id1);
	CDC_Device_SendByte(&VirtualSerial_CDC_Interface, id2);
}

/*
 * @brief Erase sector
 */
void sst39sf0x0_erase_sector(uint16_t erase_sector) {
	// instructions to erase sector
	sst39sf0x0_write_command(0x5555, 0xAA);
	sst39sf0x0_write_command(0x2AAA, 0x55);
	sst39sf0x0_write_command(0x5555, 0x80);
	sst39sf0x0_write_command(0x5555, 0xAA);
	sst39sf0x0_write_command(0x2AAA, 0x55);
	sst39sf0x0_write_command(erase_sector, 0x30);

	// count number of waiting cycles
	uint16_t cnts = sst39sf0x0_pollbyte(erase_sector);

	// return number of waiting cycles
	CDC_Device_SendByte(&VirtualSerial_CDC_Interface, cnts >> 8);
	CDC_Device_SendByte(&VirtualSerial_CDC_Interface, cnts & 0xFF);
	CDC_Device_Flush(&VirtualSerial_CDC_Interface);
}

uint16_t sst39sf0x0_pollbyte(uint16_t addr) {
	// check if DQ7 equals true data (1), else, wait until done.
	PINS_INPUT;
	uint8_t cnts = 0;     // keep track of number of polling attempts
	uint16_t pollbyte = 0;
	while((pollbyte >> 7) != 1 && cnts < 0x1000) {
		set_address(addr);
		READ_LOW;
		WAIT;
		WAIT;
		pollbyte = PIND;
		READ_HIGH;
		cnts++;
	}
	
	return cnts;
}

/*
 * @brief Write block of 256 bytes
 */
void sst39sf0x0_write_block(uint16_t start_addr) {
	// write new data
	uint16_t addr = start_addr;
	uint16_t bitsread = 0;
	
	while(bitsread < 256) {
		if(CDC_Device_BytesReceived(&VirtualSerial_CDC_Interface) > 0) {
						
			uint8_t c = CDC_Device_ReceiveByte(&VirtualSerial_CDC_Interface);
			sst39sf0x0_write_command(0x5555, 0xAA);
			sst39sf0x0_write_command(0x2AAA, 0x55);
			sst39sf0x0_write_command(0x5555, 0xA0);
			sst39sf0x0_write_command(addr, c);
				
			addr++;
			bitsread++;
			
			// since SRAM is not connected, we can use the LED to give some user feedback
			if(bitsread % 64 > 32) {
				SRAM_LOW;
			} else {
				SRAM_HIGH;
			}
		}
	}
	
	// set high at end of function
	reset_pins();
}

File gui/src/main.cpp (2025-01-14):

/****************************************************************************
 *                                                                          *
 *   GBCR                                                                   *
 *   Copyright (C) 2021 Ivo Filot <ivo@ivofilot.nl>                         *
 *                                                                          *
 *   This program is free software: you can redistribute it and/or modify   *
 *   it under the terms of the GNU Lesser General Public License as         *
 *   published by the Free Software Foundation, either version 3 of the     *
 *   License, or (at your option) any later version.                        *
 *                                                                          *
 *   This program is distributed in the hope that it will be useful,        *
 *   but WITHOUT ANY WARRANTY; without even the implied warranty of         *
 *   MERCHANTABILITY or FITNESS FOR A PARTICULAR PURPOSE.  See the          *
 *   GNU General Public License for more details.                           *
 *                                                                          *
 *   You should have received a copy of the GNU General Public license      *
 *   along with this program.  If not, see <https://www.gnu.org/licenses/>. *
 *                                                                          *
 ****************************************************************************/

#include <QApplication>
#include <QSurfaceFormat>
#include <QStatusBar>
#include <QDebug>
#include <QScreen>
#include <QStringList>

#include <iostream>
#include <iomanip>
#include <ctime>
#include <memory>

#include "mainwindow.h"
#include "config.h"

std::shared_ptr<QStringList> log_messages;

/**
 * @brief custom function for storing and display messages
 * @param type
 * @param context
 * @param msg
 */
void myMessageOutput(QtMsgType type, const QMessageLogContext &context, const QString &msg) {
    QString local_msg = QString(msg.toLocal8Bit());

    switch (type) {
    case QtDebugMsg:
        log_messages->append("[D] " + local_msg);
        std::cout << "[D] " << msg.toStdString() << std::endl;
        break;
    case QtInfoMsg:
        log_messages->append("[I] " + local_msg);
        std::cout << "[I] " << msg.toStdString() << std::endl;
        break;
    case QtWarningMsg:
        log_messages->append("[W] " + local_msg);
        std::cout << "[W] " << msg.toStdString() << std::endl;
        break;
    case QtCriticalMsg:
        log_messages->append("[C] " + local_msg);
        std::cerr << "[C] " << msg.toStdString() << std::endl;
        break;
    case QtFatalMsg:
        log_messages->append("[F] " + local_msg);
        std::cerr << "[F] " << msg.toStdString() << std::endl;
        break;
    }
}

int main(int argc, char *argv[]) {
    QApplication app(argc, argv);

    std::unique_ptr<MainWindow> mainWindow;
    log_messages = std::make_shared<QStringList>();

    try {
        // build main window
        qInstallMessageHandler(myMessageOutput);
        mainWindow = std::make_unique<MainWindow>(log_messages);
        mainWindow->setWindowTitle(QString(PROGRAM_NAME));
        mainWindow->resize(400,100);

    } catch(const std::exception& e) {
        // if any errors are caught in the process of starting up the application,
        // they will be printed in the execution.log file
        std::cerr << "Error detected!" << std::endl;
        std::cerr << e.what() << std::endl;
        std::cerr << "Abnormal closing of program." << std::endl;
    }

    mainWindow->show();

    return app.exec();
}

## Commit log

2025-01-14 Removing incompatible designs
    [dmg-gbc-cartridge-reader.kicad_pro-B_Cu.gbr, dmg-gbc-cartridge-reader.kicad_pro-B_Mask.gbr, dmg-gbc-cartridge-reader.kicad_pro-B_Paste.gbr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]
2025-01-14 Adding information for Gameboy Camera

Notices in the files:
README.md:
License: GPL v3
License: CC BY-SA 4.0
